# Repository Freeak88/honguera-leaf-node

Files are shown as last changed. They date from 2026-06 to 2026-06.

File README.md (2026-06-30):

# Honguera Leaf Node (fork de Leaf Node 3.1)

> **Fork de [leafai-io/leaf-node-v3.x](https://github.com/leafai-io/leaf-node-v3.x)** — adaptado para horticultura fungi.
>
> Créditos y licencia: Leaf AI (AGPL-3.0 FW / CERN-OHL-S v2 HW). Este fork mantiene las mismas licencias.

La **Honguera Leaf Node** es un nodo de monitoreo y control ambiental open-source para cultivo de hongos, basado en ESP32-S3. Lee sensores, publica por MQTT, y activa actuadores — diseñado para ciclos de fructificación, control de CO₂, humidificación y monitoreo de sustrato. Configuration is handled wirelessly 
via BLE, making it a self-contained building 
block for precision agriculture and 
environmental monitoring and automation systems.

Leaf Node

<!-- Hero image: replace the path below with your device photo -->
<!-- ![Leaf Node device photo](assets/hero.jpg) -->

---

## Philosophy

Leaf Node is built around one principle: **it should just work.** From first flash to live sensor data in minutes — simple enough for a grower to deploy in the field, open enough for a developer to extend and build on. No unnecessary complexity, no steep learning curve.

---

## Features

- **Multi-protocol sensor support** — I2C, RS485, SDI-12, OneWire on a single board
- **MQTT telemetry** — publishes sensor data and heartbeats, receives commands
- **OTA firmware updates** — triggered via MQTT command, no physical access needed
- **BLE provisioning** — initial Wi-Fi and MQTT setup from the companion app, no serial cable required
- **Scheduling** — DAC and actuator outputs can be programmed on a time-based schedule
- **Smart control** — MOSFET and relay outputs with duration-based switching
- **Node chaining** — UART-based daisy-chain for multi-node deployments
- **Watchdog & health monitoring** — automatic recovery with exponential backoff on sensor errors
- **Factory mode** — serial-console provisioning for production flashing

---

## Hardware

Leaf Node PCB

### Overview

| Component | Details |
|---|---|
| MCU | ESP32-S3 |
| Status LED | WS2812B addressable RGB (v3) |
| RS485 | Half-duplex, DE/RE controlled |
| I2C | SDA GPIO8, SCL GPIO9 |
| SDI-12 | GPIO12 (shared with OneWire via hardware bridge) |
| OneWire | GPIO12 |
| Actuators | MOSFET (GPIO36), Relay (GPIO38), DAC (MCP4725 via I2C) |
| PWM | GPIO2 (1 kHz, 10-bit) + MOSFET gate (5 kHz, 10-bit) |

Leaf Node Pinout

### Supported Sensors

| Sensor | Interface | Wiring | Measurement |
|---|---|---|---|
| SHT31  | I2C (0x44) | +3.3V · GND · SDA · SCL | Temperature, Humidity |
| EZO pH | I2C (0x63) | +3.3V · GND · SDA · SCL | pH |
| EZO EC | I2C (0x64) | +3.3V · GND · SDA · SCL | Electrical Conductivity |
| TEROS 12 | SDI-12 | +3.3V · GND · SDI-12 | Soil moisture, temperature, EC |
| DS18B20 | OneWire | +3.3V · GND · Need Modification | Temperature |
| SLT5007 | RS485 | +3.3V · GND · A · B | VWC, Bulk EC, Soil temperature, Pore EC |
| CWT-PSS | RS485 | +12V · GND · A · B | PAR (Photosynthetically Active Radiation) |
| LEAFTHSN | RS485 | +12V · GND · A · B | Leaf wetness, Leaf temperature |
| CWT-SoilTHS | RS485 | +12V · GND · A · B | VWC, Soil temperature |
| CWT-THXXS | RS485 | +12V · GND · A · B | Air temperature, Humidity, VPD |

### Actuators

| Actuator | GPIO / Interface | Wiring | Typical Use |
|---|---|---|---|
| MOSFET | GPIO36 | +12V · -PWR | Pumps, fans, DC loads |
| Relay | GPIO38 | COM · NO · NC | AC/DC switching, high-current loads |
| DAC (MCP4725) | I2C (0x60) | 0-10V · GND | Analog 0–5 V output (e.g. dosing pumps) |
| PWM | GPIO2 | IO2 · GND | Variable speed / dimming control |

### PCB & Enclosure

Leaf Node Assembly

- KiCad project: [hardware/pcb/kiCad/](hardware/pcb/kiCad/)
- Enclosure STL/STEP files: [hardware/enclosure/](hardware/enclosure/)
---

## Getting Started

### Option A — Web Flasher (recommended)

No toolchain required. Works directly in Chrome/Edge.

1. **Get the hardware** — order a ready-to-use Leaf Node at [Build Your Leaf Node](https://leafai.io/build-node.html), or fabricate your own PCB from the [KiCad files](hardware/pcb/kiCad/)
2. Open the **[Leaf AI Firmware Flasher](https://leafai.io/firmware-flasher.html)** and follow the on-screen steps
3. Open the Leaf AI app, tap **Add Device**, and provision Wi-Fi via BLE

That's it — the node connects to the Leaf AI backend and starts publishing sensor data.

> A free Leaf AI account is required to use the app. Sign up directly in the Leaf AI app.

---

### Option B — Build from source (PlatformIO)

For developers who want to modify or extend the firmware.

**Prerequisites:** [PlatformIO](https://platformio.org/) (CLI or VS Code extension)

#### 1. Assemble the hardware

Fabricate the PCB from the files in [hardware/pcb/](hardware/pcb/) and wire your sensors according to the pin table above.

#### 2. Flash the firmware

> **First flash:** Use the **[Leaf AI Firmware Flasher](https://leafai.io/firmware-flasher.html)** for the initial flash. It writes a compatible serial number to the device that is required for communication with the Leaf AI app. Subsequent builds can be uploaded via PlatformIO.

```bash
git clone https://github.com/leafai-io/leaf-node-v3.1.git
cd leaf-node-v3.1
pio run --target upload
```

Monitor serial output (115200 baud):

```bash
pio device monitor
```

#### 3. Provision via BLE

Open the Leaf AI app, tap **Add Device**, and follow the on-screen steps to configure Wi-Fi and link your account.

---

## Using with the App

Leaf AI App

Once your Leaf Node is provisioned, open the Leaf AI app to view live sensor readings, configure schedules, and control actuators — all from your phone.

---

## License

This project uses two open-source licences depending on what you are working with:

| Component | Licence |
|---|---|
| Firmware / Software | [GNU AGPL-3.0](licenses/LICENSE-SOFTWARE) |
| Hardware (PCB, enclosure) | [CERN-OHL-S v2](licenses/LICENSE-HARDWARE) |

**Software (AGPL-3.0):** You can use, modify, and distribute the firmware freely, but any modified version you run as a networked service must also be released under the same licence.

**Hardware (CERN-OHL-S v2):** You can study, modify, and manufacture the hardware freely, but any modified design you distribute or produce must be released under the same licence with complete source files.

**If you create a fork, we'd love to hear about it.** Open an issue or send us a message so we can showcase your project and potentially integrate useful improvements.

---

## Support

Leaf AI is an independent, open-source project. If you find it useful, you can support its continued development at [Leaf AI Support](https://leafai.io/support.html).

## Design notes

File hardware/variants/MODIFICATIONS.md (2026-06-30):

# Honguera Leaf Node Modifications Guide

## Lite (`honguera-lite/`)
**Automated:** DAC, RS485, SDI-12, step-down regulator, extra MOSFET, extra relay, extra TVS removed.

**Manual KiCad needed:**
1. Add **MH-Z19B CO₂** → 4-pin header on UART2 (GPIO18 RX, GPIO19 TX)
2. Add **SSR** for humidifier → one free GPIO
3. Replace step-down → **AMS1117-3.3** (SOT-223)
4. Compact PCB ~30-40%
5. Remove redundant text labels & test points

## Pro (`honguera-pro/`)
**Automated:** Title/project metadata updated. All components kept.

**Manual KiCad needed:**
1. Add **MH-Z19B CO₂** → 4-pin header UART2
2. Add **SSR footprint** → AC humidifier control
3. Add **MPXV7002DP** → differential pressure (analog ADC)
4. Add **DS3231 RTC** → I2C bus
5. Add **5-pin expansion header** (+5V, GND, GPIO, SDA, SCL)

## Firmware targets (PlatformIO)
```ini
[env:honguera-lite]
board = esp32-s3-devkitc-1
build_flags = -DHONGUERA_LITE

[env:honguera-pro]
board = esp32-s3-devkitc-1
build_flags = -DHONGUERA_PRO
```

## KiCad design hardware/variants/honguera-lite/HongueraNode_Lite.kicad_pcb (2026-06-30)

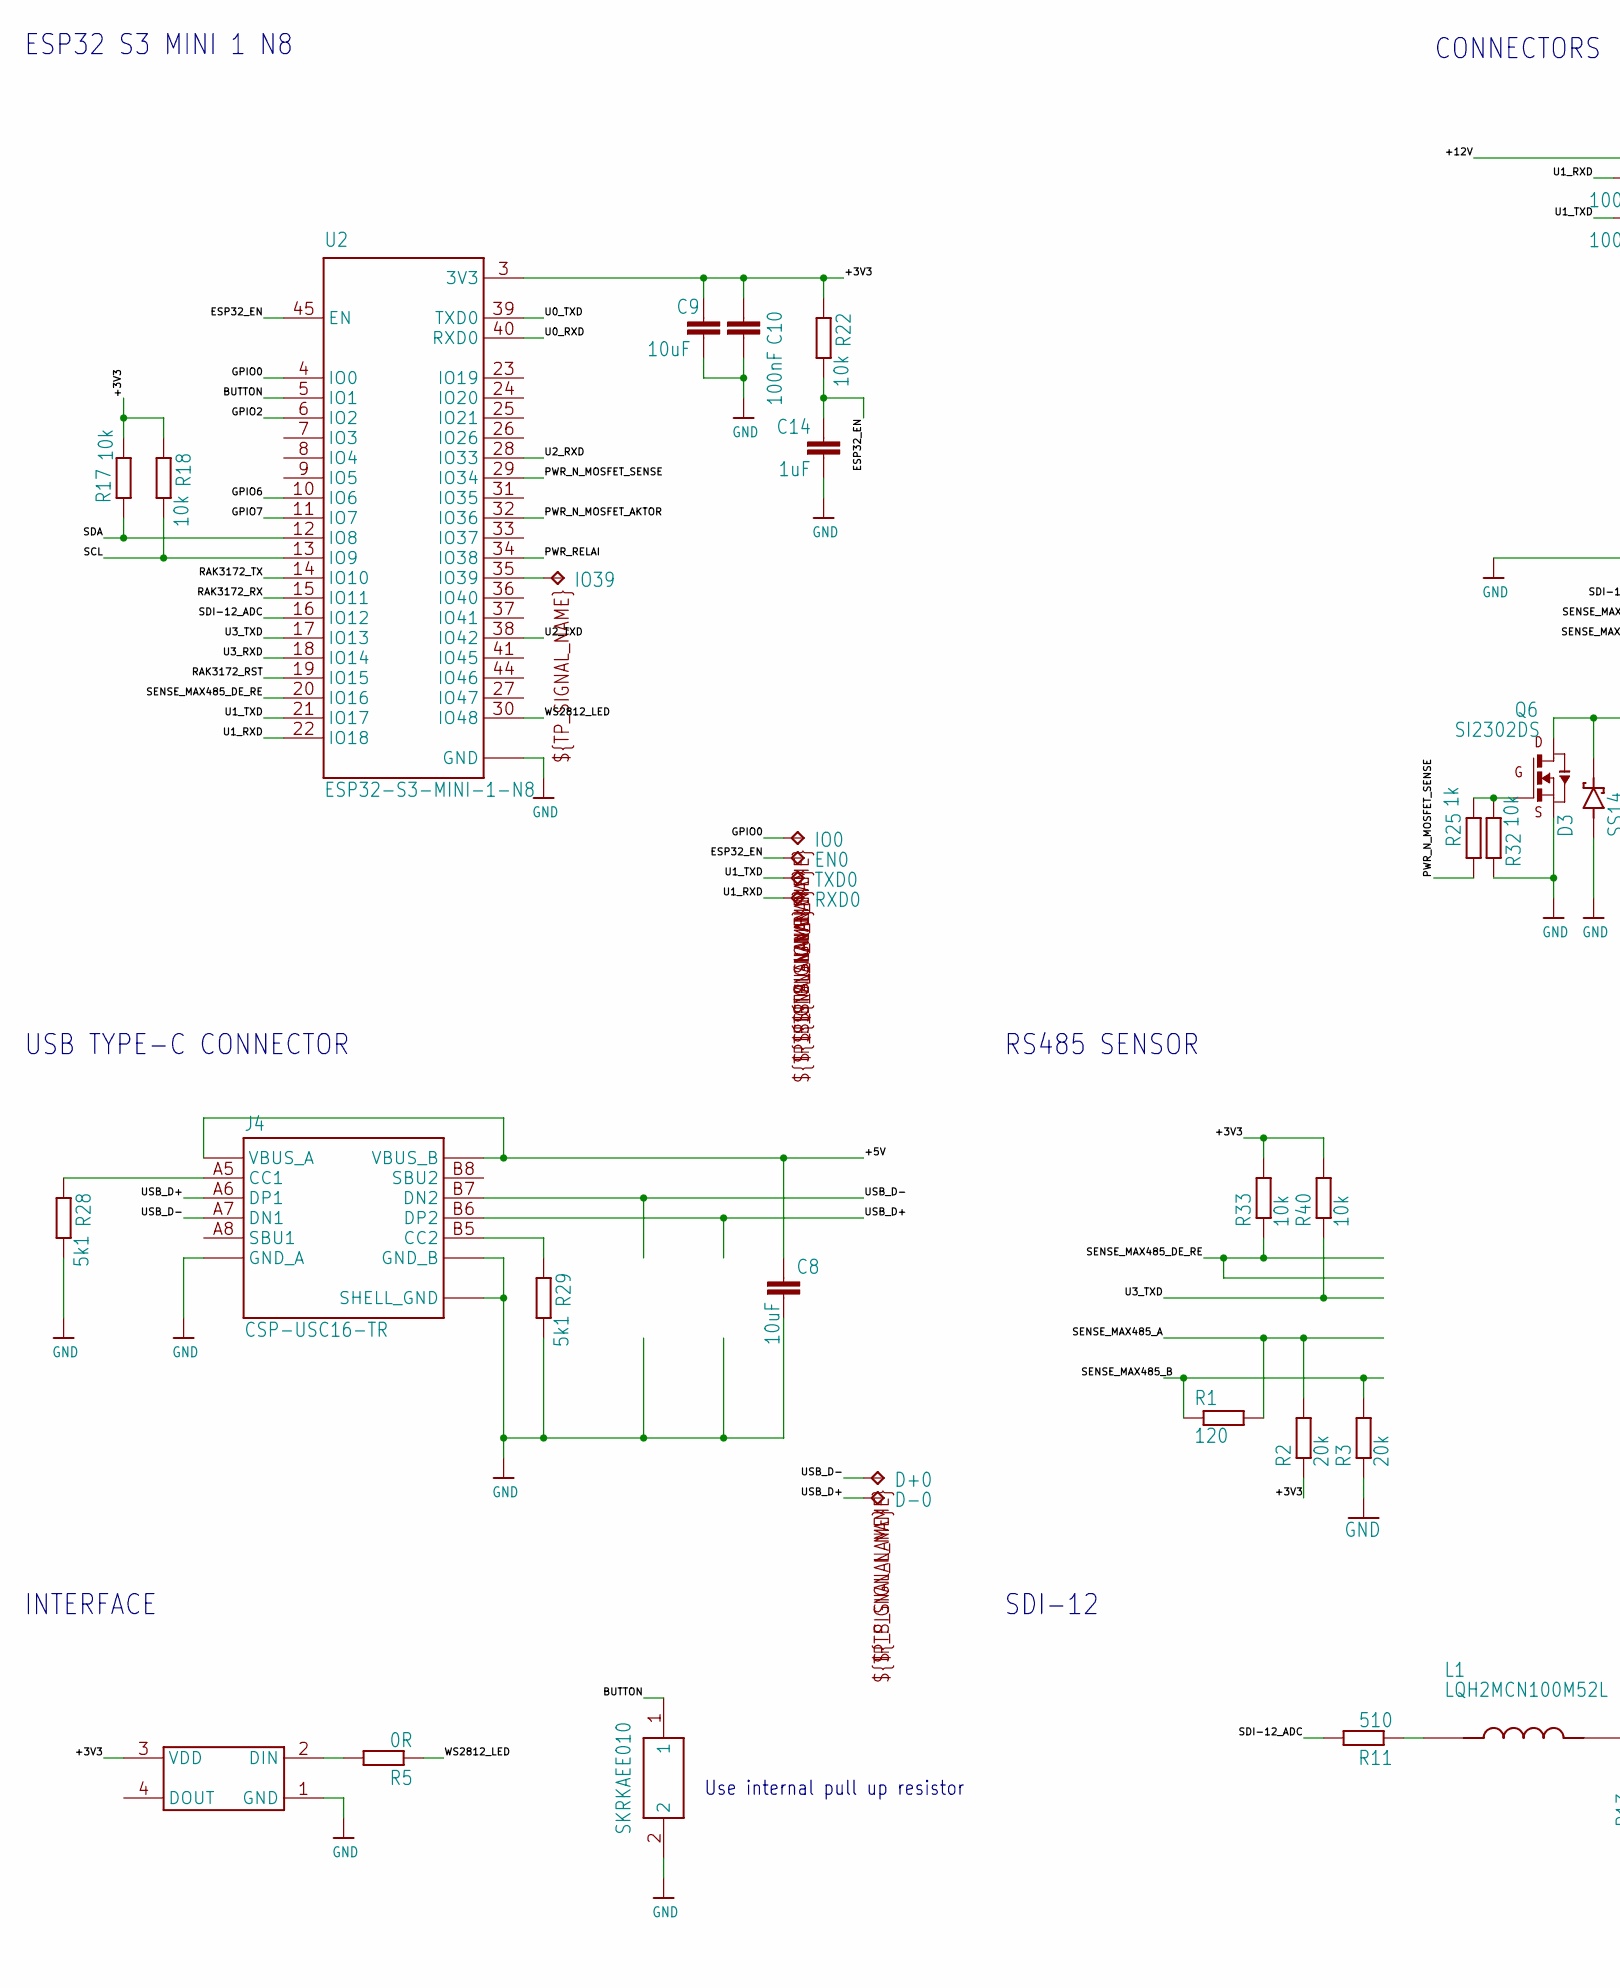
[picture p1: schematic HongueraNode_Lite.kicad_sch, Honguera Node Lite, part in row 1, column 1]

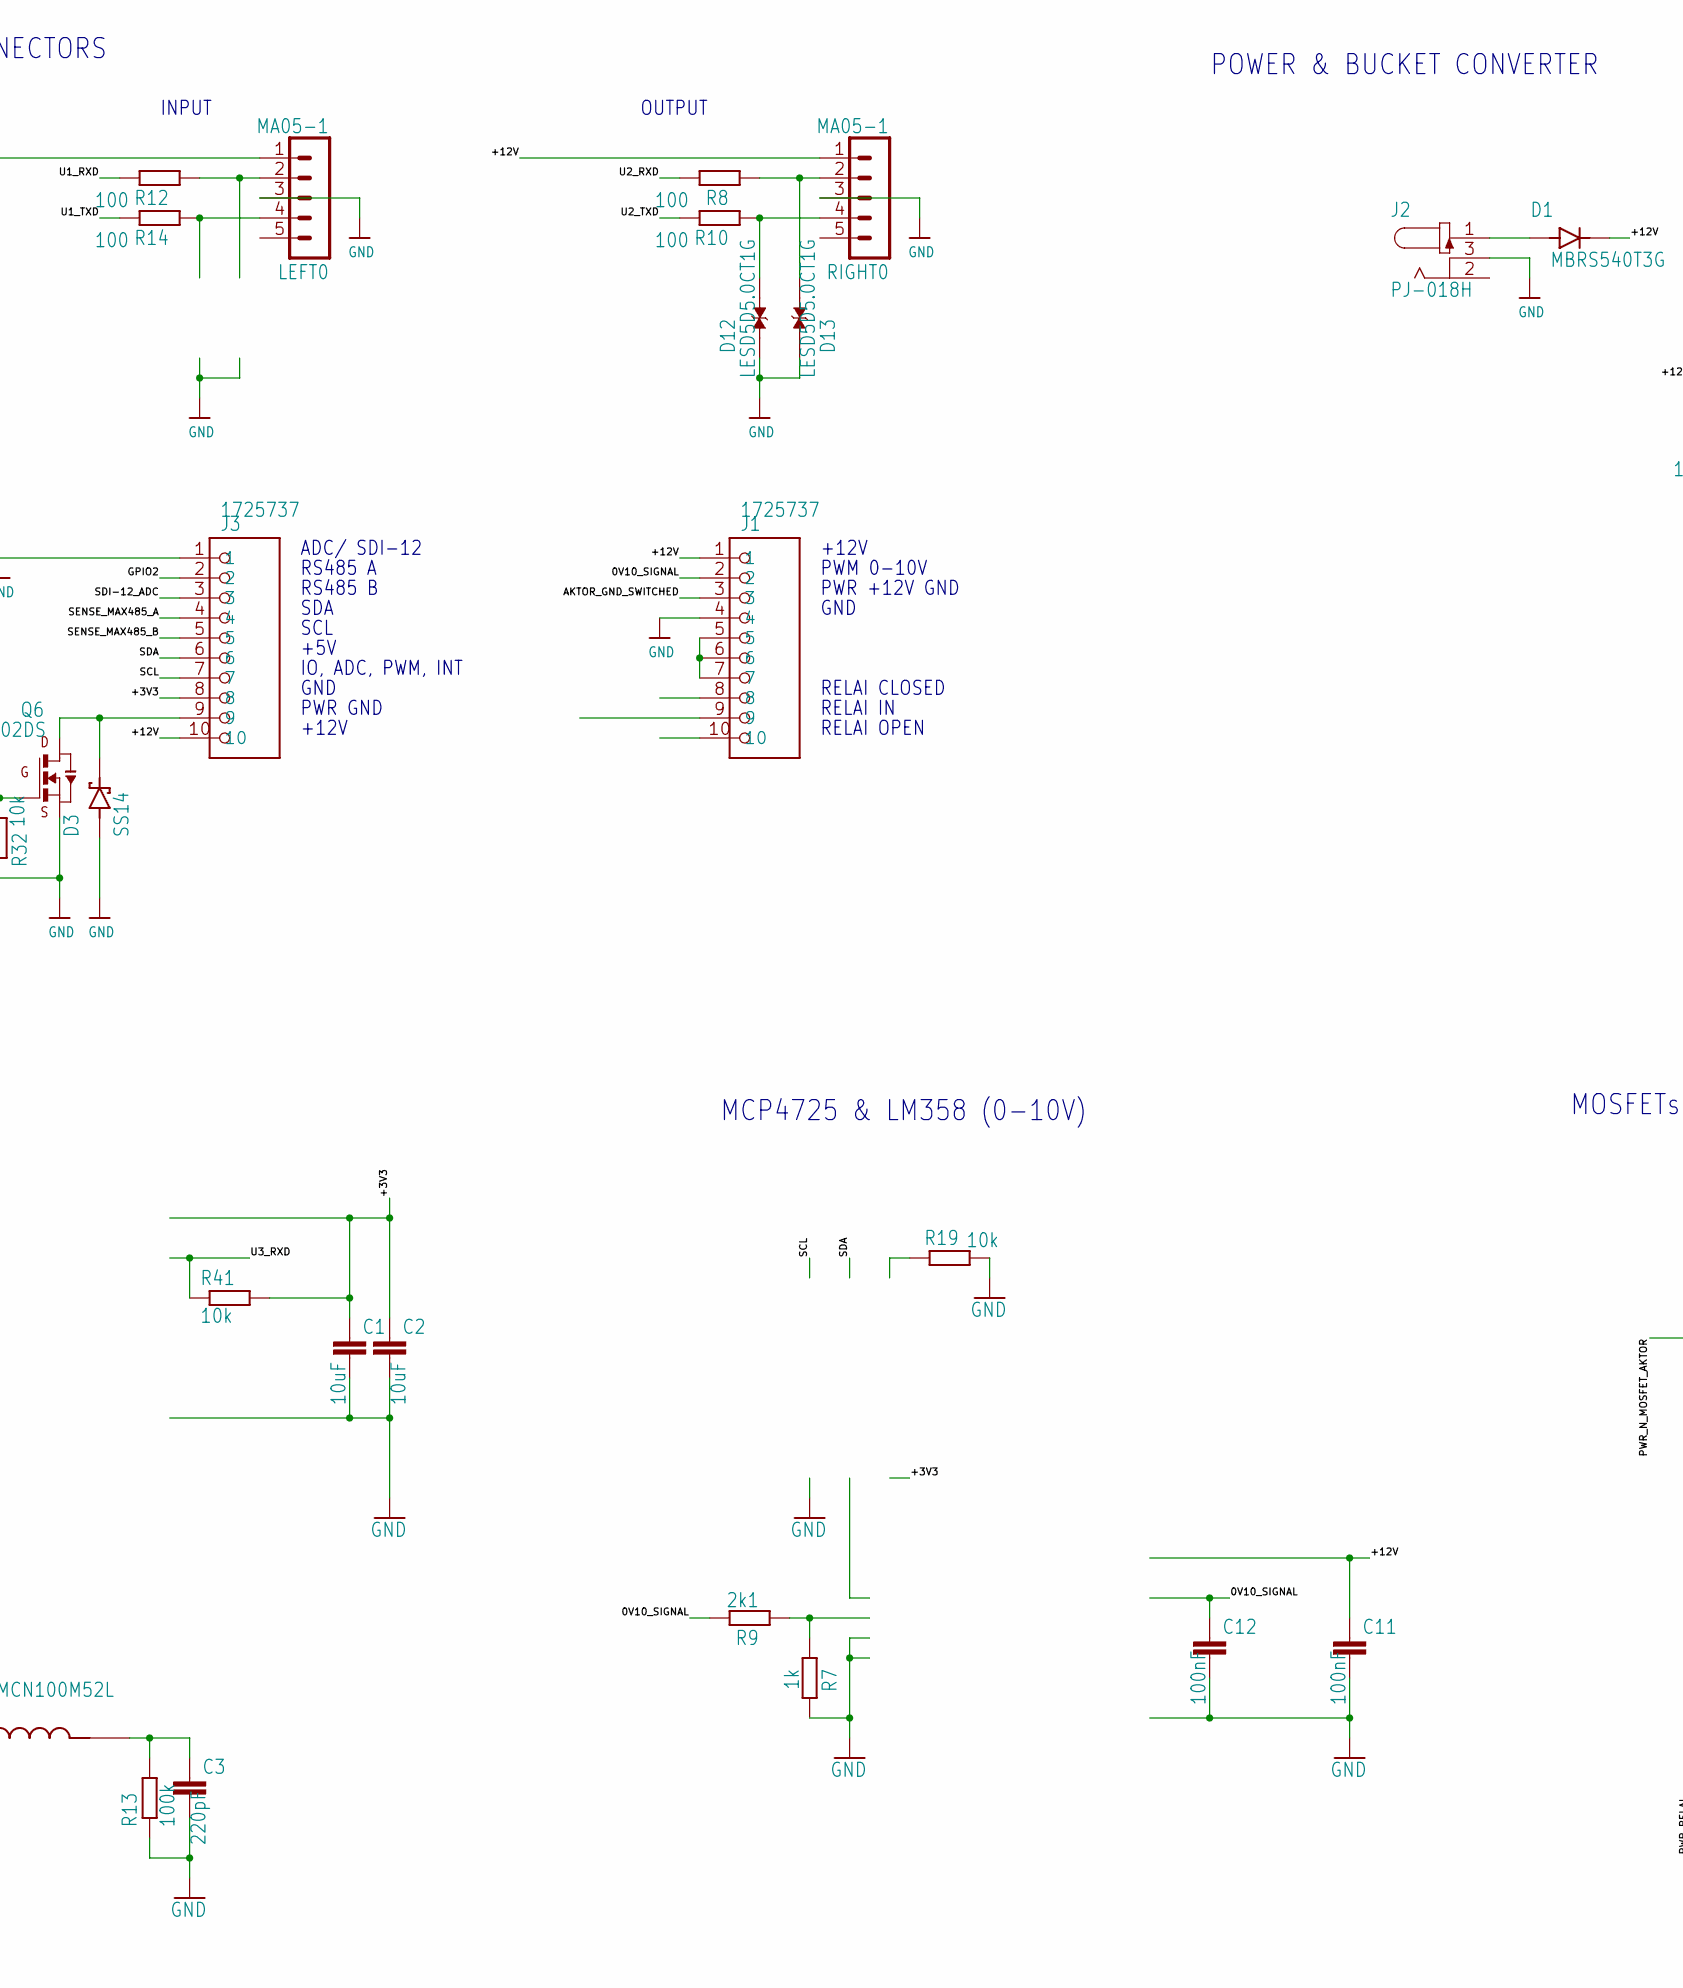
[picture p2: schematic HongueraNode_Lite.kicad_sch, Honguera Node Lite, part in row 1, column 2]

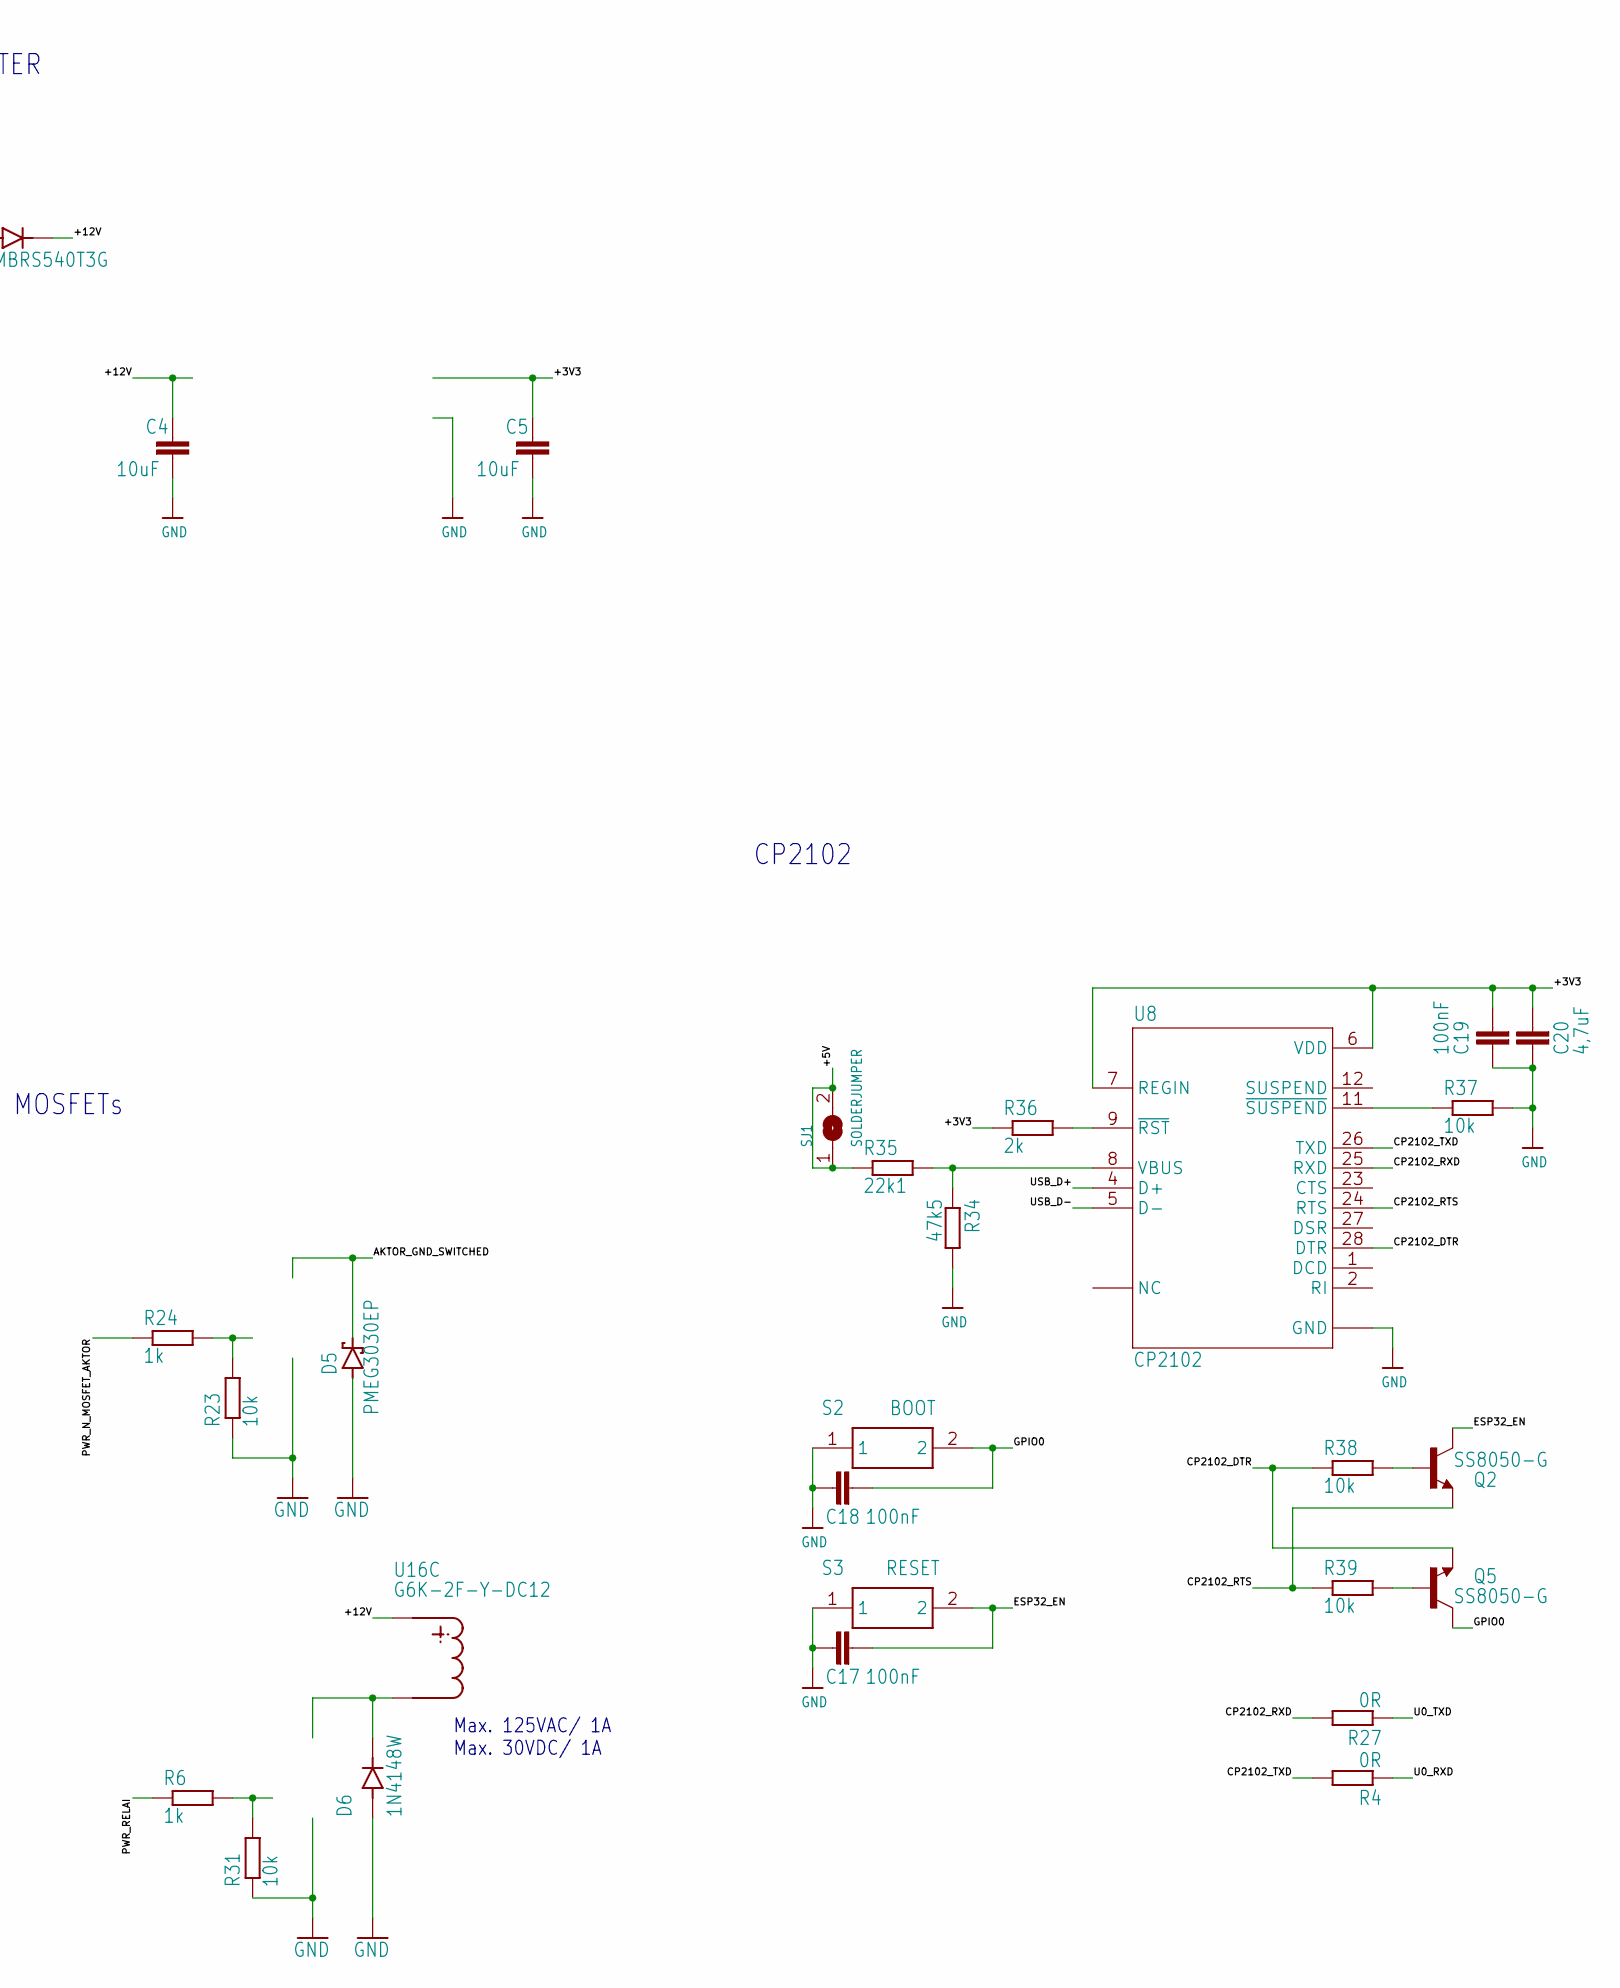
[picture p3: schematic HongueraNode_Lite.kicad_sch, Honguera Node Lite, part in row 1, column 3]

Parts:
C1, C2, C4, C5, C8, C9: 10uF; C0603
C3: 220pF; C0603
C10, C11, C12, C17, C18, C19: 100nF; C0603
C14: 1uF; C0603
C20: 4,7uF; C0603
D1: MBRS540T3G; DIOM7959X261N
D3: SS14; DIOM4325X250N
D5: PMEG3030EP; SOD_128
D6: 1N4148W; SODFL3816X120N
D7: SK68XXMINI-HS; 3535
D12, D13: LESD5D5.0CT1G; TVS_LESD5D5.0CT1G
D+0: TPTP13R; TP13R
D-0: TPTP13R; TP13R
EN0: TPTP13R; TP13R
IO0, IO39: TPTP13R; TP13R
J1, J3: 1725737; PHOENIX_1725737
J2: PJ-018H; CUI_PJ-018H
J4: CSP-USC16-TR; VALCON_CSP-USC16-TR
L1: LQH2MCN100M52L; IND_LQH2MCN100M52L
LEFT0: MA05-1
Q2, Q5: SS8050-G; TRANS_SS8050-G
Q6: SI2302DS; SOT23-3_TO-236AB
R1: 120; R0402
R2, R3: 20k; R0402
R4, R5, R27: 0R; R0402
R6, R7, R24, R25: 1k; R0402
R8, R10, R12, R14: 100; R0402
R9: 2k1; R0402
R11: 510; R0402
R13: 100k; R0402
R17, R18, R19, R22, R23, R31, R32, R33, R37, R38, R39, R40, R41: 10k; R0402
R28, R29: 5k1; R0402
R34: 47k5; R0402
R35: 22k1; R0402
R36: 2k; R0402
RIGHT0: MA05-1
RXD0: TPTP13R; TP13R
S1: SKRKAEE010; SKRK
S2: BOOT; SKRK
S3: RESET; SKRK
SJ1: SOLDERJUMPER; SOLDERJUMPER_ARROW_NOPASTE
TXD0: TPTP13R; TP13R
U2: ESP32-S3-MINI-1-N8; XCVR_ESP32-S3-MINI-1-N8
U8: CP2102; QFN50P500X500X100-29N
U16: G6K-2F-Y-DC12; G6K

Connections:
0V10_SIGNAL: C12.1, J1.2, R9.2; also elsewhere on the board
+3V3: C1.1, C2.1, C5.1, C9.1, C10.1, C19.2, C20.2, D7.3 (VDD), J3.8, R2.1, R17.1, R18.2, R22.2, R33.2, R36.1, R40.2, R41.2, U2.3 (3V3), U8.6 (VDD), U8.7 (REGIN); also elsewhere on the board
+5V: C8.1, J4.A4 (VBUS_A), J4.A9 (VBUS_A), J4.B4 (VBUS_B), J4.B9 (VBUS_B), R35.1, SJ1.1, SJ1.2
+12V: C4.1, C11.1, D1.1 (C), J1.1, J3.10, LEFT0.1, RIGHT0.1, U16.1 (COIL+); also elsewhere on the board
AKTOR_GND_SWITCHED: D5.C, J1.3; also elsewhere on the board
BUTTON: S1.1, U2.5 (IO1)
CP2102_DTR: Q5.2 (E), R38.1, U8.28 (DTR)
CP2102_RTS: Q2.2 (E), R39.1, U8.24 (RTS)
CP2102_RXD: R27.2, U8.25 (RXD)
CP2102_TXD: R4.2, U8.26 (TXD)
ESP32_EN: C14.1, C17.2, EN0.TP, Q2.3 (C), R22.1, S3.2, U2.45 (EN)
GND: C1.2, C2.2, C3.2, C4.2, C5.2, C8.2, C9.2, C10.2, C11.2, C12.2, C14.2, C17.1, C18.1, C19.1, C20.1, D3.A, D5.A, D6.A, D7.1 (GND), D12.2, D13.2, J1.4, J2.3, J3.1, J4.A1 (GND_A), J4.A12 (GND_A), J4.B1 (GND_B), J4.B12 (GND_B), J4.S1 (SHELL_GND), J4.S2 (SHELL_GND), J4.S3 (SHELL_GND), J4.S4 (SHELL_GND), LEFT0.3, Q6.2 (S), R3.1, R7.2, R13.1, R19.1, R23.1, R28.1, R29.1, R31.1, R32.1, R34.2, R37.2, RIGHT0.3, S1.2, S2.1, S3.1, U2.1 (GND), U2.2 (GND), U2.42 (GND), U2.43 (GND), U2.46 (GND), U2.47 (GND), U2.48 (GND), U2.49 (GND), U2.50 (GND), U2.51 (GND), U2.52 (GND), U2.53 (GND), U2.54 (GND), U2.55 (GND), U2.56 (GND), U2.57 (GND), U2.58 (GND), U2.59 (GND), U2.60 (GND), U2.61 (GND), U2.61_1 (GND), U2.61_2 (GND), U2.61_3 (GND), U2.61_4 (GND), U2.61_5 (GND), U2.61_6 (GND), U2.61_7 (GND), U2.61_8 (GND), U2.62 (GND), U2.63 (GND), U2.64 (GND), U2.65 (GND), U8.3 (GND), U8.29 (GND); also elsewhere on the board
GPIO0: C18.2, IO0.TP, Q5.3 (C), S2.2, U2.4 (IO0)
GPIO2: J3.2, U2.6 (IO2)
GPIO6: U2.10 (IO6)
GPIO7: U2.11 (IO7)
unnamed 17: R7.1, R9.1; also elsewhere on the board
unnamed: J1.5, J1.6, J1.7
unnamed 19: R19.2; also elsewhere on the board
unnamed: D7.2 (DIN), R5.2
unnamed: R37.1, U8.11 (~SUSPEND)
unnamed: L1.1, R11.1
unnamed: C3.1, L1.2, R13.2
unnamed: D3.C (K), J3.9, Q6.3 (D)
unnamed: Q6.1 (G), R25.2, R32.2
unnamed: R36.2, U8.9 (~RST)
unnamed: R34.1, R35.2, U8.8 (VBUS)
unnamed: IO39.TP, U2.35 (IO39)
unnamed: Q2.1 (B), R38.2
unnamed: Q5.1 (B), R39.2
unnamed: J1.9, U16.3 (COMMON)
unnamed 32: R23.2, R24.2; also elsewhere on the board
unnamed: J1.8, U16.4 (CONTACT_NO)
unnamed: J1.10, U16.2 (CONTACT_NC)
unnamed 35: D6.C (K), U16.8 (COIL-); also elsewhere on the board
unnamed 36: R6.2, R31.2; also elsewhere on the board
unnamed: D1.2 (A), J2.1
unnamed: J4.A5 (CC1), R28.2
unnamed 39: LEFT0.2, R12.1; also elsewhere on the board
unnamed: J4.B5 (CC2), R29.2
unnamed 41: LEFT0.4, R14.1; also elsewhere on the board
unnamed: D13.1, R8.1, RIGHT0.2
unnamed: D12.1, R10.1, RIGHT0.4
PWR_N_MOSFET_AKTOR: R24.1, U2.32 (IO36)
PWR_N_MOSFET_SENSE: R25.1, U2.29 (IO34)
PWR_RELAI: R6.1, U2.34 (IO38)
RAK3172_RST: U2.19 (IO15)
RAK3172_RX: U2.15 (IO11)
RAK3172_TX: U2.14 (IO10)
SCL: J3.7, R18.1, U2.13 (IO9); also elsewhere on the board
SDA: J3.6, R17.2, U2.12 (IO8); also elsewhere on the board
SDI-12_ADC: J3.3, R11.2, U2.16 (IO12)
SENSE_MAX485_A: J3.4, R1.2, R2.2; also elsewhere on the board
SENSE_MAX485_B: J3.5, R1.1, R3.2; also elsewhere on the board
SENSE_MAX485_DE_RE: R33.1, U2.20 (IO16); also elsewhere on the board
U0_RXD: R4.1, U2.40 (RXD0)
U0_TXD: R27.1, U2.39 (TXD0)
U1_RXD: R12.2, RXD0.TP, U2.22 (IO18)
U1_TXD: R14.2, TXD0.TP, U2.21 (IO17)
U2_RXD: R8.2, U2.28 (IO33)
U2_TXD: R10.2, U2.38 (IO42)
U3_RXD: R41.1, U2.18 (IO14); also elsewhere on the board
U3_TXD: R40.1, U2.17 (IO13); also elsewhere on the board
USB_D+: D-0.TP, J4.A6 (DP1), J4.B6 (DP2), U8.4 (D+); also elsewhere on the board
USB_D-: D+0.TP, J4.A7 (DN1), J4.B7 (DN2), U8.5 (D-); also elsewhere on the board
WS2812_LED: R5.1, U2.30 (IO48)

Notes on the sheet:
MOSFETs
RELAI IN
+12V
PWR +12V GND
PWR GND
RS485 SENSOR
Use internal pull up resistor
SDA
MCP4725 & LM358 (0-10V)
+5V
RS485 B
RELAI CLOSED
GND
OUTPUT
SDI-12
ESP32 S3 MINI 1 N8
CP2102
CONNECTORS
INTERFACE
RELAI OPEN
POWER & BUCKET CONVERTER
PWM 0-10V
USB TYPE-C CONNECTOR
Max. 125VAC/ 1A Max. 30VDC/ 1A
IO, ADC, PWM, INT
ADC/ SDI-12
INPUT
RS485 A
SCL

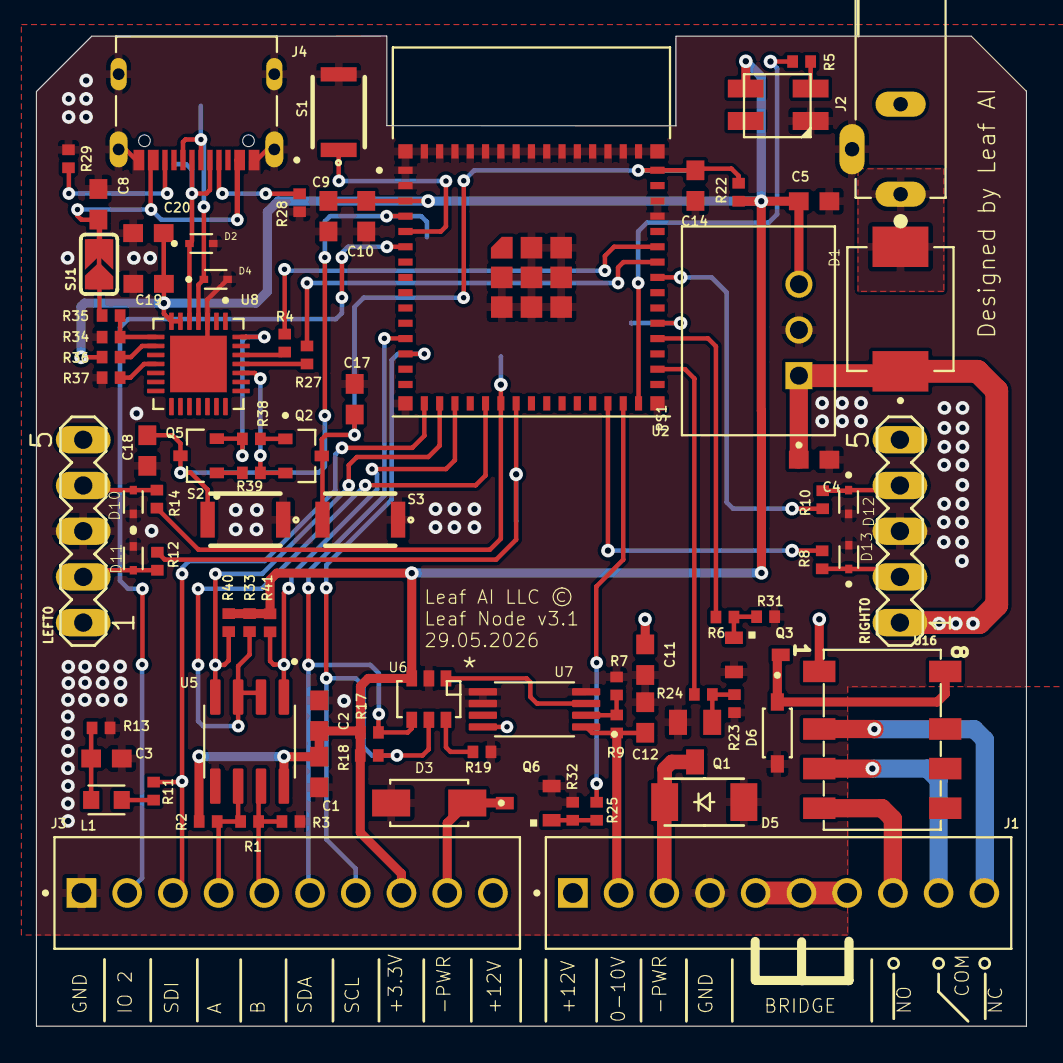
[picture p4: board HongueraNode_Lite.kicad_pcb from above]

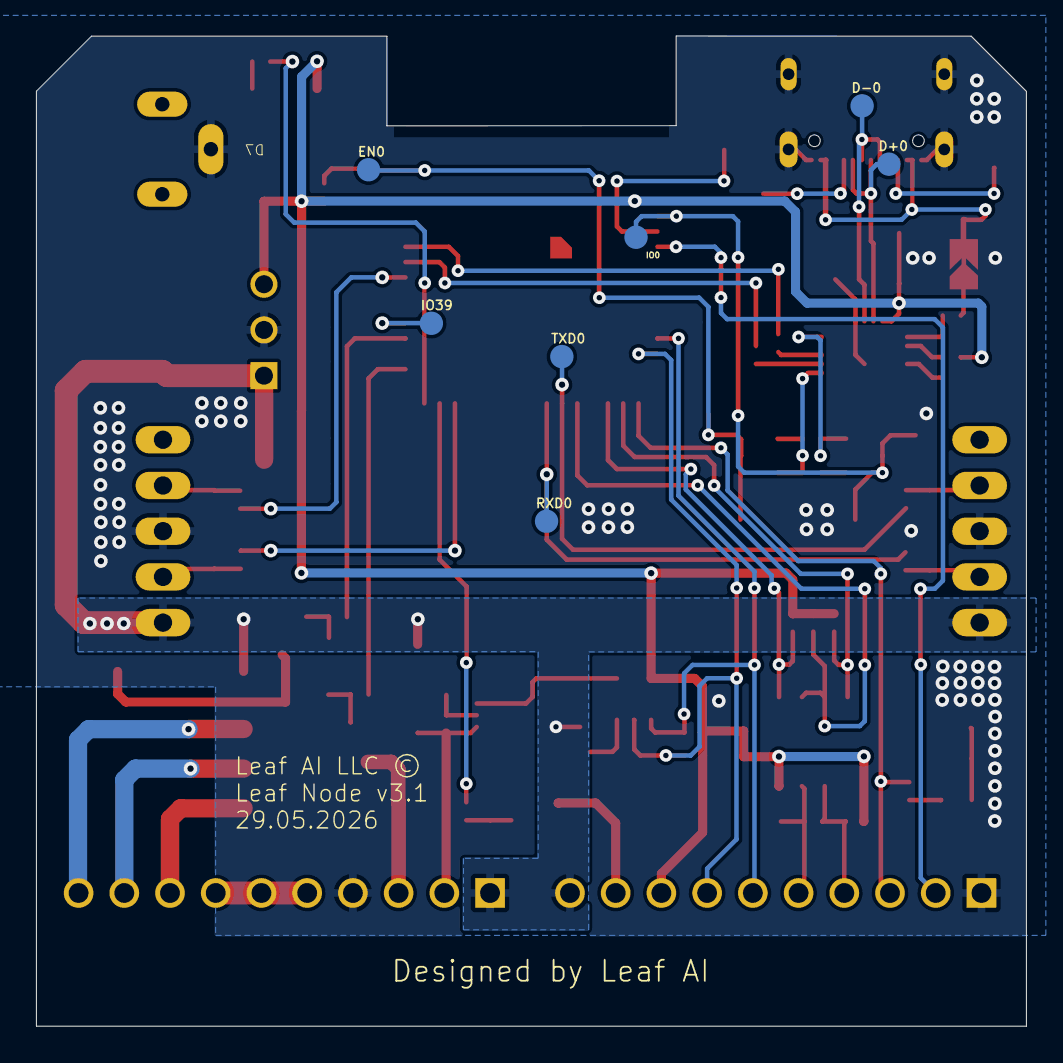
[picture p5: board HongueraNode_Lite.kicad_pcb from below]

Board: 2 copper layers, 55.0 x 55.0 mm, 91 parts (7 on the bottom side), 62 nets.

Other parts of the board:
D2, D4, D10, D11: LESD5D5.0CT1G; TVS_LESD5D5.0CT1G
PS1: R-78E3.3-1.0; CONV_R-78E3.3-1.0
Q1: IRLML6344; SOT23
Q3: SI2302DS; SOT23-3_TO-236AB
U5: MAX485ESA+T; SOIC127P600X175-8N
U6: MCP4725A1T-E/CH; SOT23-6
U7: LM358PW; SOP65P640X120-8N

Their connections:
0V10_SIGNAL: U7.1; also elsewhere on the board
+3V3: PS1.3, U5.8, U6.3; also elsewhere on the board
+12V: PS1.1, U7.8; also elsewhere on the board
AKTOR_GND_SWITCHED: Q1.3; also elsewhere on the board
GND: D2.2, D4.2, D10.1, D11.1, PS1.2, Q1.2, Q3.2, U5.5, U6.2, U7.4, U7.5, U7.6; also elsewhere on the board
unnamed: U6.1, U7.3
unnamed 17: U7.2; also elsewhere on the board
unnamed 19: U6.6; also elsewhere on the board
unnamed 32: Q1.1; also elsewhere on the board
unnamed 35: Q3.3; also elsewhere on the board
unnamed 36: Q3.1; also elsewhere on the board
unnamed 39: D11.2; also elsewhere on the board
unnamed 41: D10.2; also elsewhere on the board
SCL: U6.5; also elsewhere on the board
SDA: U6.4; also elsewhere on the board
SENSE_MAX485_A: U5.6; also elsewhere on the board
SENSE_MAX485_B: U5.7; also elsewhere on the board
SENSE_MAX485_DE_RE: U5.2, U5.3; also elsewhere on the board
U3_RXD: U5.1; also elsewhere on the board
U3_TXD: U5.4; also elsewhere on the board
USB_D+: D4.1; also elsewhere on the board
USB_D-: D2.1; also elsewhere on the board

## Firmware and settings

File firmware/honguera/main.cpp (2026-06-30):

#include <Arduino.h>
#include "HongueraNode.h"

HongueraNode* node = nullptr;

void setup() {
    node = new HongueraNode();
    if (!node->initialize()) {
        Serial.println("FATAL: HongueraNode init failed! Rebooting...");
        delay(5000);
        ESP.restart();
    }
}

void loop() {
    if (node) node->update();
    delay(1);
}

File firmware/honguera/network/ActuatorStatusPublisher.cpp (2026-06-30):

#include "ActuatorStatusPublisher.h"
#include "../hardware/PWMController.h"
#include "config.h"

ActuatorStatusPublisher::ActuatorStatusPublisher(RuntimeConfig* config, MQTTManager* mqttManager, 
                                                 Logger* logger, Actuator* actuator, void* mcp4725,
                                                 PWMController* pwmController, PWMController* pwmControllerMOSFET)
    : config_(config), mqttManager_(mqttManager), logger_(logger), actuator_(actuator), mcp4725_(mcp4725),
      pwmController_(pwmController), pwmControllerMOSFET_(pwmControllerMOSFET) {
}

ActuatorStatusPublisher::~ActuatorStatusPublisher() {
}

bool ActuatorStatusPublisher::publishStatus(const String& lastCommand, const String& lastTarget, 
                                           const String& lastTimestamp, const String& actuatorType,
                                           bool isRamping, float rampTargetValue, 
                                           uint32_t rampDurationSeconds, uint32_t rampElapsedSeconds) {
    if (!mqttManager_) {
        if (logger_) {
            logger_->error("ActuatorStatusPublisher", "MQTT manager not available");
        }
        return false;
    }
    
    if (!actuator_) {
        if (logger_) {
            logger_->error("ActuatorStatusPublisher", "Actuator not available");
        }
        return false;
    }
    
    String topic = getStatusTopic();
    String payload = buildStatusPayload(lastCommand, lastTarget, lastTimestamp, actuatorType,
                                       isRamping, rampTargetValue, rampDurationSeconds, rampElapsedSeconds);
    
    if (topic.isEmpty() || payload.isEmpty()) {
        if (logger_) {
            logger_->error("ActuatorStatusPublisher", "Empty topic or payload");
        }
        return false;
    }
    
    if (logger_) {
        logger_->info("ActuatorStatusPublisher", "Publishing actuator status to: " + topic);
        logger_->debug("ActuatorStatusPublisher", "Payload: " + payload);
    }
    
    bool result = mqttManager_->publish(topic, payload, false);
    
    if (result) {
        if (logger_) {
            logger_->info("ActuatorStatusPublisher", "Actuator status published successfully");
        }
    } else {
        if (logger_) {
            logger_->error("ActuatorStatusPublisher", "Failed to publish actuator status");
        }
    }
    
    return result;
}

String ActuatorStatusPublisher::getStatusTopic() const {
    if (!config_ || config_->getSerialNumber().isEmpty()) {
        if (logger_) {
            logger_->error("ActuatorStatusPublisher", "Serial number not configured");
        }
        return "";
    }
    
    // Topic format: lai/devices/{serial}/status
    return "lai/devices/" + config_->getSerialNumber() + "/status";
}

String ActuatorStatusPublisher::buildStatusPayload(const String& lastCommand, const String& lastTarget, 
                                                   const String& lastTimestamp, const String& actuatorType,
                                                   bool isRamping, float rampTargetValue, 
                                                   uint32_t rampDurationSeconds, uint32_t rampElapsedSeconds) {
    DynamicJsonDocument doc(1024);
    
    // Device section
    JsonObject device = doc.createNestedObject("device");
    device["serial"] = config_ ? config_->getSerialNumber() : "UNKNOWN";
    device["name"] = "Leaf Node";
    device["firmware"] = FIRMWARE_VERSION;
    device["uptime"] = millis() / 1000;  // Convert to seconds
    
    // Network section
    JsonObject network = doc.createNestedObject("network");
    network["wifi_ssid"] = WiFi.SSID();
    network["ip_address"] = WiFi.localIP().toString();
    network["rssi"] = WiFi.RSSI();
    network["mac_address"] = WiFi.macAddress();
    
    // Only include the specific actuator type that changed, or both if not specified
    bool includeMosfet = actuatorType.isEmpty() || actuatorType.equalsIgnoreCase("mosfet");
    bool includeRelay = actuatorType.isEmpty() || actuatorType.equalsIgnoreCase("relay");
    
    // MOSFET section (only if relevant)
    if (includeMosfet) {
        JsonObject mosfet = doc.createNestedObject("mosfet");
        mosfet["state"] = actuator_ ? actuator_->getState(Actuator::Type::MOSFET) : false;
        if (actuator_ && actuator_->isTimerActive(Actuator::Type::MOSFET)) {
            mosfet["timer_active"] = true;
            uint32_t remainingMillis = actuator_->getRemainingMillis(Actuator::Type::MOSFET);
            
            mosfet["timer_remaining_ms"] = remainingMillis;
        } else {
            mosfet["timer_active"] = false;
        }
    }
    
    // Relay section (only if relevant)
    if (includeRelay) {
        JsonObject relay = doc.createNestedObject("relay");
        relay["state"] = actuator_ ? actuator_->getState(Actuator::Type::RELAY) : false;
        if (actuator_ && actuator_->isTimerActive(Actuator::Type::RELAY)) {
            relay["timer_active"] = true;
            uint32_t remainingMillis = actuator_->getRemainingMillis(Actuator::Type::RELAY);
            
            relay["timer_remaining_ms"] = remainingMillis;
        } else {
            relay["timer_active"] = false;
        }
    }
    
    // DAC section (if available and DAC-related actuatorType OR general status)
    bool isDACStatus = actuatorType.equalsIgnoreCase("dac") || 
                       actuatorType.startsWith("dac_") ||
                       isRamping ||
                       actuatorType.isEmpty(); // Include DAC in general status
    if (mcp4725_ && isDACStatus) {
        JsonObject dac = doc.createNestedObject("dac");
        dac["value"] = mcp4725_->getCurrentValue();
        dac["voltage"] = mcp4725_->getCurrentVoltage();
        dac["percent"] = mcp4725_->getCurrentPercent();
        dac["last_command_type"] = mcp4725_->getLastCommandType();
        
        // Add ramping info if active
        if (isRamping) {
            dac["ramping"] = true;
            dac["ramp_duration_seconds"] = rampDurationSeconds;
            dac["ramp_elapsed_seconds"] = rampElapsedSeconds;
            
            // Add target value based on last command type
            String commandType = mcp4725_->getLastCommandType();
            if (commandType == "voltage") {
                dac["ramp_target_voltage"] = rampTargetValue;
            } else if (commandType == "percent") {
                dac["ramp_target_percent"] = rampTargetValue;
            } else if (commandType == "value") {
                dac["ramp_target_value"] = (uint16_t)rampTargetValue;
            }
        }
    }
    
    // PWM section (if available and PWM-related actuatorType OR general status)
    bool isPWMStatus = actuatorType.equalsIgnoreCase("pwm") || 
                       actuatorType.startsWith("pwm_") ||
                       actuatorType.isEmpty(); // Include PWM in general status
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

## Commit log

2026-06-30 feat: add Honguera Lite and Pro HW variants
    - Lite: remove DAC, RS485, SDI-12, step-down regulator, extra MOSFET/relay/TVS
    - Pro: all components kept, title updated
    - Variant generator script for reproducible builds
    - Modification guide for manual KiCad adjustments
    [HongueraNode_Lite.kicad_pcb, HongueraNode_Lite.kicad_sch, HongueraNode_Pro.kicad_pcb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]
2026-06-30 feat: add Honguera firmware with CO2, fruiting cycle, PID
    - MH-Z19B CO2 sensor driver (UART)
    - Fruiting cycle state machine (colonization → initiation → fruiting → harvest)
    - Humidity PID controller
    - HongueraNode class (clean slate from Leaf AI infra)
    - Dual env: honguera-lite / honguera-pro
    - Kept Leaf AI core: WiFi, MQTT, BLE, OTA, SHT31, DS18B20, actuators
2026-06-30 feat: add HongueraNode.cpp implementation
    - Adapted from LeafNode.cpp: removed MCP4725, RS485, SDI-12, chain discovery, WebServer
    - Added: MH-Z19B CO2 sensor init, FruitingCycle, HumidityPID
    - Added: readAndPublishSensors() with fungi-specific telemetry (CO2, phase, PID)
    - Compact MQTT payload with all sensor readings
    - LeafNode.h compat alias for SerialCommandHandler
2026-06-30 refactor: deep clean RS485/SDI-12/MCP4725/UARTChain refs from Honguera firmware
    - All RS485Manager, SDI12Manager, MCP4725, UARTChainManager refs removed
    - SensorManager: stripped RS485/SDI-12 bus switching, unused sensor types
    - SystemManager: MCP4725 and chain manager killed
    - CommandHandler: DAC command handling neutered
    - ScheduleManager: DAC params nulled
    - ActuatorStatusPublisher: MCP4725 replaced with void*
    - Cleanup script preserved for reproducibility
    [ActuatorStatusPublisher.cpp, CommandHandler.cpp, ScheduleManager.cpp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]
